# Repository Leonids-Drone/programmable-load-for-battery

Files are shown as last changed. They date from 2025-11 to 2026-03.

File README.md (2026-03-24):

## Specification
For prototype board

**Maximum input voltage (VBUS):** 30v

**Maximum continous current:** 50a

**Peak current:** 200a

## Control method
check programmable load - control board

## Cooling method
Water cooling or heat sink

load-control-board-v1

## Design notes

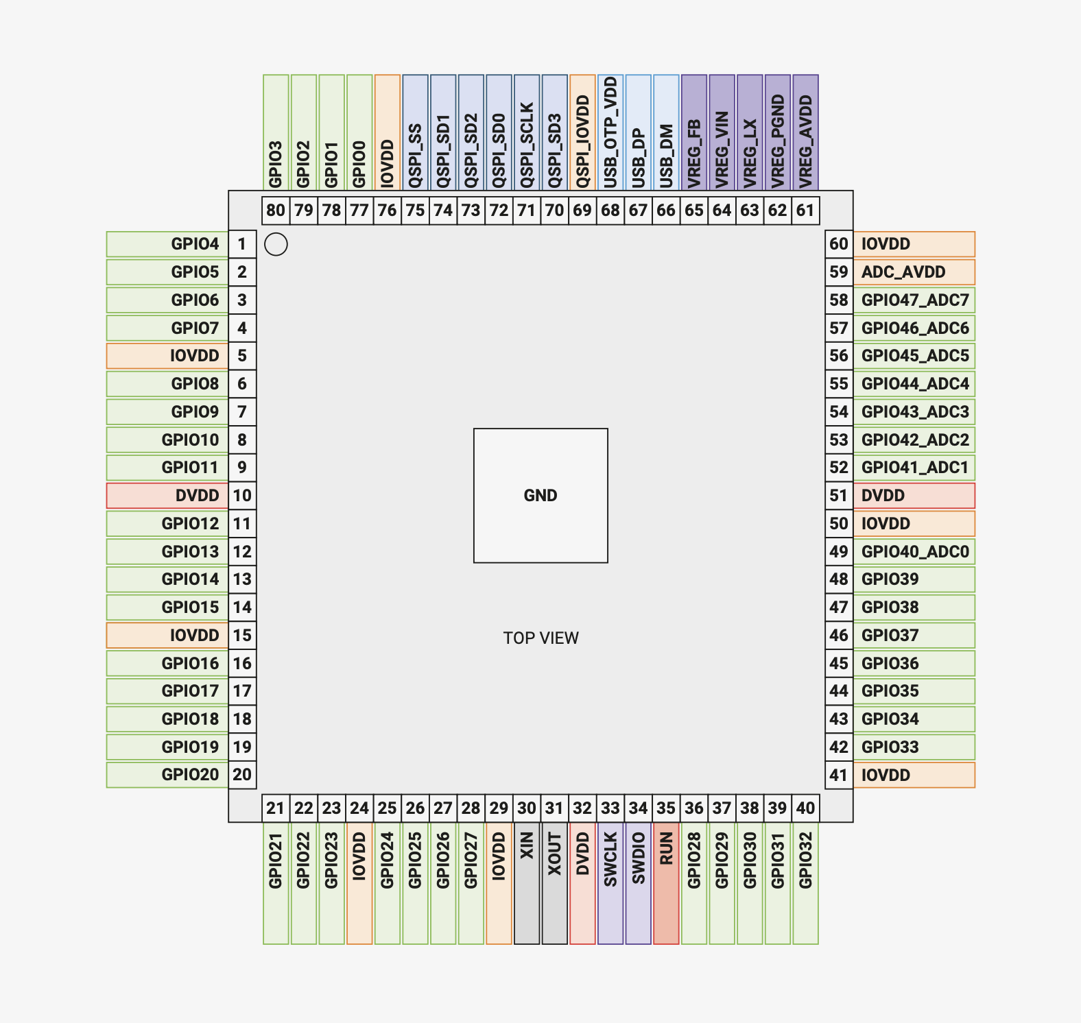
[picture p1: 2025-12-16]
digital-control-board/jpg/rp2350_pinout.png

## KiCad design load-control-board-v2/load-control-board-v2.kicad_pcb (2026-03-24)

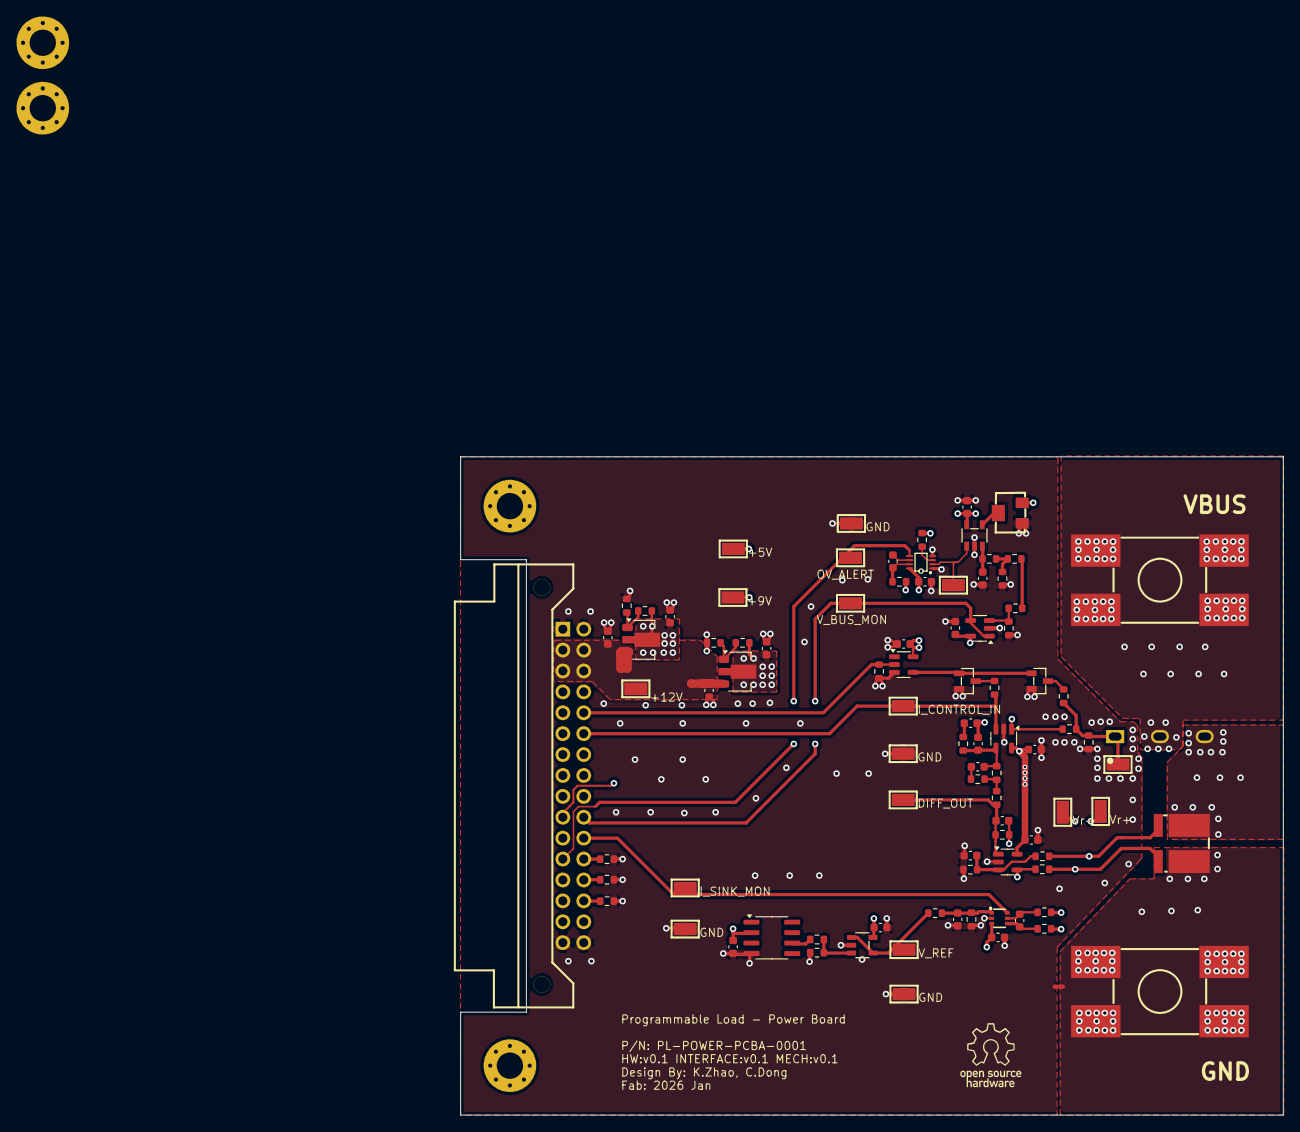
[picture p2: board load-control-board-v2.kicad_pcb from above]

Board: 4 copper layers, 100.0 x 80.0 mm, 96 parts (0 on the bottom side), 45 nets.

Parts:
C1, C2, C4, C5, C7, C9, C10, C11, C12, C14, C17, C21: 100n; C_0603_1608Metric
C3, C6, C8, C49: 1u; C_0603_1608Metric
C13, C15: 100p; C_0603_1608Metric
C16: 47n; C_0603_1608Metric
C18: 1n; C_0603_1608Metric
C19, C20: 10n; C_0603_1608Metric
C53: 1u; R_0603_1608Metric
CN1: 3511232BMRS0BNA2; CONN-TH_3511232BMRS0BNA2
CN2, CN3: BTC22M4NBB4SCM; CONN-SMD_L10.8-W10.0-LS17.4
H1, H5, H9, H13: MountingHole_Pad; MountingHole_3.2mm_M3_Pad_Via
NT1: NetTie_2; NetTie-2_SMD_Pad0.5mm
Q1, Q2: AO3400A; SOT-23-3_L2.9-W1.3-P1.90-LS2.4-BR
Q3: IRFP7530PBF; PG-TO247-3_L15.9-W5.2-P5.44-L_1_Horizontal
R1: R; R_0603_1608Metric
R2, R6: 240; R_0603_1608Metric
R3: 720; R_0603_1608Metric
R4: 11k; R_0603_1608Metric
R5, R12, R15, R17, R18, R22, R25: 1k; R_0603_1608Metric
R7: 1488; R_0603_1608Metric
R8, R19, R24, R27, R28: 0; R_0603_1608Metric
R9: 3224W-1-103E; RES-ADJ-SMD_3224W
R10, R13, R29, R76, R77, R78: 10k; R_0603_1608Metric
R11: 24k; R_0603_1608Metric
R14: 11.5k; R_0603_1608Metric
R16, R20: 40k; R_0603_1608Metric
R21: 47; R_0603_1608Metric
R23: 500; R_0603_1608Metric
R26, R72: 100; R_0603_1608Metric
R_SHUNT1: BVB-M-R001-1.0; RES-SMD_4P-L6.9-W6.6_SBB-K-2F-N-T5
TP0a1: I_SINK_MON; SMD_RH-5015
TP0c1: I_CONTROL_IN; SMD_RH-5015
TP1: +12v; SMD_RH-5015
TP2: DIFF_OUT; SMD_RH-5015
TP3: MOS_G; SMD_RH-5015
TP10: +5v; SMD_RH-5015
TP11: +9v; SMD_RH-5015
TP12: V_SHUNT_P; SMD_RH-5015
TP16: V_SHUNT_N; SMD_RH-5015
TP20, TP21, TP22, TP26: GND; SMD_RH-5015
TP30: REF; SMD_RH-5015
TP31: V_BUS_MON; SMD_RH-5015
TP32: VBUS_COMP_OUT; SMD_RH-5015
TP33: OV_ALERT; SMD_RH-5015
U1, U3: LM317_SOT-223; SOT-89-3
U2: 74AHC1G04; SOT-23-5
U5: REF5025AD; SOIC-8_3.9x4.9mm_P1.27mm
U6: SN74LVC1G123DCUR_C352969; VSSOP-8_L2.3-W2.0-P0.50-LS3.1-BL
U7: ALERT_COMP_OUT; SOT-23-5_L2.9-W1.6-P0.95-LS2.8-TL
U8, U10, U11: OPA188xxDBV; TSOT-23-5
U12: INA186A1IDCKR; SC-70-6_L2.2-W1.3-P0.65-LS2.1-BR
U22: TL081HIDBVR; SOT-23-5_L2.9-W1.6-P0.95-LS2.8-TL

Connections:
+5V: C2.2, C3.1, C7.2, C8.1, C10.2, C12.2, C21.2, C49.1, CN1.10 (A10), R2.1, R9.3, R10.1, R13.2, TP10.1, U1.2 (VO), U2.5 (VCC), U5.2 (Vin), U6.8 (VCC), U7.5 (V+), U8.5 (V+), U12.3 (VS), U22.5 (V+)
+9V: C6.1, C14.2, C17.2, R6.1, TP11.1, U3.2 (VO), U10.5 (V+), U11.5 (V+)
+12V: C1.1, C4.1, CN1.2 (A2), CN1.3 (A3), CN1.18 (B2), CN1.19 (B3), TP1.1, U1.3 (VI), U3.3 (VI)
/I_SINK_MON_CH0: CN1.27 (B11), TP0a1.1, U12.6 (OUT)
/I_SINK_MON_CH1: CN1.28 (B12), R76.1
/I_SINK_MON_CH2: CN1.29 (B13), R77.1
/I_SINK_MON_CH3: CN1.30 (B14), R78.1
/ch0/MOS_G: Q3.1 (G), R24.2, R26.2, R29.2, TP3.1
/ch0/V_REF_FIL: C11.1, C53.1, R72.2, U12.1 (REF)
/ch0/V_Rs0n: R18.2, R28.2, R_SHUNT1.3, TP16.1
/ch0/V_Rs0p: R17.2, R27.2, R_SHUNT1.4, TP12.1
ENABLE: CN1.21 (B5), R1.1, U2.2
GND: C1.2, C2.1, C3.2, C4.2, C5.1, C6.2, C7.1, C8.2, C10.1, C11.2, C12.1, C13.2, C14.1, C17.1, C21.1, C49.2, C53.2, CN1.1 (A1), CN1.16 (A16), CN1.17 (B1), CN1.32 (B16), NT1.2, Q1.2 (S), Q2.2 (S), R1.2, R3.2, R5.1, R7.2, R9.1, R12.2, R15.1, R16.2, R29.1, R76.2, R77.2, R78.2, TP20.1, TP21.1, TP22.1, TP26.1, U2.3 (GND), U5.4 (GND), U6.1 (~A), U6.4 (GND), U7.2 (V-), U8.2 (V-), U10.2 (V-), U11.2 (V-), U12.2 (GND), U22.2 (V-)
GNDPWR: CN3.1, CN3.2, CN3.3, CN3.4, NT1.1, R_SHUNT1.2
I_CONTROL: CN1.22 (B6), R19.2, TP0c1.1, U11.3 (+)
unnamed: C15.1, R20.1, R21.2, TP2.1, U10.1
unnamed: C16.2, R22.1
unnamed: C18.1, C19.1, R26.1, U11.1
unnamed: C19.2, R25.2
unnamed: Q1.3 (D), R19.1
unnamed: Q2.3 (D), R24.1
unnamed: Q3.3 (S), R_SHUNT1.1
unnamed: R4.2, R5.2, R8.1
unnamed: R21.1, R22.2, R23.2
unnamed: R2.2, R3.1, U1.1 (ADJ)
unnamed: R6.2, R7.1, U3.1 (ADJ)
unnamed: R11.1, U5.6 (Vout)
unnamed: TP32.1, U6.2 (B), U7.1 (OUT)
unnamed: C9.2, U6.6 (Cext)
unnamed: C9.1, R13.1, U6.7 (Rext/Cext)
unnamed: R10.2, U6.3 (~CLR)
unnamed: C5.2, R8.2, U7.3 (IN+)
unnamed: R9.2, U7.4 (IN-)
unnamed: R14.2, R15.2, U8.3 (+)
unnamed: C13.1, R16.1, R17.1, U10.3 (+)
unnamed: C15.2, R18.1, R20.2, U10.4 (-)
unnamed: C16.1, C18.2, R23.1, R25.1, U11.4 (-)
unnamed: C20.1, R27.1, U12.4 (IN+)
unnamed: C20.2, R28.1, U12.5 (IN-)
unnamed: R11.2, R12.1, U22.3 (IN+)
OV_ALERT: CN1.12 (A12), TP33.1, U6.5 (Q)
VBUS: CN2.1, CN2.2, CN2.3, CN2.4, Q3.2 (D), R4.1, R14.1
V_BUS_MON: CN1.26 (B10), TP31.1, U8.1, U8.4 (-)
V_REF: R72.1, TP30.1, U22.1 (OUT), U22.4 (IN-)
~ENABLE: Q1.1 (G), Q2.1 (G), U2.4

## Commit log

2025-11-27 Simple voltage source
    [hybrid-resistor-mosfet-simulate.kicad_sch]
2025-11-27 Update gitignore
    [hybrid-resistor-mosfet-simulate.kicad_sch]
2025-11-27 add ignore
    [hybrid-resistor-mosfet-simulate.kicad_sch]
2025-12-01 Tuning the LC value
    [hybrid-resistor-mosfet-simulate.kicad_sch]
2025-12-08 create load board v1
    [hybrid-resistor-mosfet-simulate.kicad_sch, load-control-board-v1.kicad_pcb, load-control-board-v1.kicad_sch]
2025-12-08 opamp part
    [load-control-board-v1.kicad_sch]
2025-12-09 Add digital-control-board
    [digital-control-board.kicad_pcb, digital-control-board.kicad_sch]
2025-12-09 delet digital control board
    [digital-control-board.kicad_pcb, digital-control-board.kicad_sch]
2025-12-09 Get some design from rp minimal board
    [digital-control-board.kicad_sch]
2025-12-09 Update sch
    [digital-control-board.kicad_sch]
2025-12-09 communicate 1
    [load-control-board-v1.kicad_sch]
2025-12-12 Update digital-control-board
    [digital-control-board.kicad_sch]
2025-12-12 Create simulation and move relative files
    [hybrid-resistor-mosfet-simulate.kicad_pcb, hybrid-resistor-mosfet-simulate.kicad_sch, mosfet-ina-simulation.kicad_pcb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]
2025-12-12 simulation double opamp
    [mosfet-ina-simulation.kicad_sch]
2025-12-13 sch half complete
    [load-control-board-v1.kicad_sch]
2025-12-13 First try of two stage opa
    [mosfet-ina-simulation.kicad_sch]
2025-12-14 ac analysis
    [mosfet-ina-simulation.kicad_sch]
2025-12-14 Add simulate parameters
    [mosfet-ina-simulation.kicad_sch]
2025-12-14 Add ADC input filter
    [digital-control-board.kicad_pcb, digital-control-board.kicad_sch]
2025-12-16 pre-final sch
    add channel 0-4
    [load-control-board-v1.kicad_sch]
2025-12-16 push channel.kiacd_sch
    [channel.kicad_sch]
2025-12-16 temp push
    [analog_interface.kicad_sch, connector.kicad_sch, mosfet_gate_interface.kicad_sch]
2025-12-17 Edit multi opamp
    [channel.kicad_sch, load-control-board-v1.kicad_sch]
2025-12-17 Rearrange design in load control board, need further check
    [analog_interface.kicad_sch, channel.kicad_sch, load-control-board-v1.kicad_sch]
2025-12-19 Sch pre-finish, without connector label
2025-12-19 Move to layout stage
    [channel.kicad_sch, load-control-board-v1.kicad_pcb, load-control-board-v1.kicad_sch]
2025-12-24 initial layout
    [channel.kicad_sch, load-control-board-v1.kicad_pcb, load-control-board-v1.kicad_sch]
2025-12-25 final layout and initial connecting
    [load-control-board-v1.kicad_pcb]
2025-12-25 Import from Dong's windows computer lib
    [load-control-board-v1.kicad_pcb]
2026-01-02 Add connector
    [load-control-board-v1.kicad_pcb, load-control-board-v1.kicad_sch]
2026-01-02 edit esc-lib
2026-01-06 Reset lib to useable state, add C963694 and C963693 to lib
    git restore --source 2908f185c442d5d7c429a6014c4036d19cda51b5 -- /Users/kelvin-zhao/Development/git/_Leonids/programmable-load-for-battery/programmable-load-library.kicad_sym
2026-01-07 Define the connector pinout to control board, import current connector
    [channel.kicad_sch, load-control-board-v1.kicad_pcb, load-control-board-v1.kicad_sch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]
2026-01-07 layout before check
    [channel.kicad_sch, load-control-board-v1.kicad_pcb, load-control-board-v1.kicad_sch]
2026-01-07 layout adjust
    [load-control-board-v1.kicad_pcb]
2026-01-07 Section upload
    Monostable Multivibrator for OV, VBUS scale resistor network and buffer Opa
    [load-control-board-v1.kicad_pcb]
2026-01-08 Change layout of LDO and VBUS monitor
    [load-control-board-v1.kicad_pcb]
2026-01-08 Add filled zone for mosfet, change terminal to from THO to SMT
    [channel.kicad_sch, load-control-board-v1.kicad_pcb, load-control-board-v1.kicad_sch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]
2026-01-09 Complete second times layout (no copper filled)
    [channel.kicad_sch, load-control-board-v1.kicad_pcb, load-control-board-v1.kicad_sch]
2026-01-10 connection and drc check
    connection of power layer is done
    drc checked
    [load-control-board-v1.kicad_pcb]
2026-01-11 First complete PCB, DRC check complete
    [load-control-board-v1.kicad_sch]
2026-01-11 Add design info and logo
    [load-control-board-v1.kicad_pcb, power_connector.kicad_sch]
2026-01-11 Correcr INA186A1IDCKR to A2
    50V/V is the correct gain
    [load-control-board-v1.kicad_pcb]
2026-01-11 Change INA back to 25V/V, change diff gain to 1:40
    [channel.kicad_sch, connector.kicad_sch, load-control-board-v1.kicad_pcb]
2026-03-16 Add 4channel
    [channel.kicad_sch, load-control-board-v1.kicad_pcb, load-control-board-v1.kicad_sch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]
2026-03-24 Move from load-control-board-v1 to v2
    [channel.kicad_sch, load-control-board-v1.kicad_pcb, load-control-board-v1.kicad_sch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]
2026-03-24 Add 2011 heat sink
    [load-control-board-v2.kicad_pcb]
